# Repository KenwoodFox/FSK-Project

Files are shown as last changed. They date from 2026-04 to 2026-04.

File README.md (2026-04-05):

# FSK Analog Project

Done for EG330L at SNHU

# To Quickly Look At the design

Schematic [HERE](https://kicanvas.org/?repo=https://github.com/KenwoodFox/FSK-Project/blob/main/FSK%20Project.kicad_sch)  
PCB [HERE](https://kicanvas.org/?repo=https://github.com/KenwoodFox/FSK-Project/blob/main/FSK%20Project.kicad_pcb)

# To xmit the entire bee movie script
(the only valid benchmark ofc)

```shell
curl -s https://gist.githubusercontent.com/MattIPv4/045239bc27b16b2bcf7a3a9a4648c08a/raw/2411e31293a35f3e565f61e7490a806d4720ea7e/bee%2520movie%2520script | tee /dev/ttyUSB5
```

# Sending Serial/Testing

Configure Serial first

```shell
❯ minicom --device /dev/ttyUSB0 --baudrate 1200
```

Then you can cat+tee into the sender

```shell
❯ cat monk_syllabus.txt | tee /dev/ttyUSB0
```

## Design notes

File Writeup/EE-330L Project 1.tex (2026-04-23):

\documentclass[aspectratio=169]{beamer}
\usetheme{Berlin}

\usepackage{graphicx}
\usepackage{siunitx}
\usepackage{tikz}
\usepackage{qrcode}
% Do not store QR bitstrings in the .aux file (they are huge). A truncated .aux
% from an interrupted build causes ``File ended while scanning \qr@savematrix''.
% Tradeoff: each run recomputes QR codes (slightly slower, much more robust).
\makeatletter
\long\def\qr@writebinarymatrixtoauxfile#1{}%
\makeatother
\usepackage{acronym}

% Define acronyms without printing a list (immediate; \ac{...} works on first compile).
\newacro{FSK}{frequency-shift keying}
\newacro{PLL}{phase-locked loop}
\newacro{VCO}{voltage-controlled oscillator}

\title{Analog Project}
\subtitle{FSK Modulator and Demodulator}
\author{Joe Sedutto}
\institute{Southern New Hampshire University \and EE-330L --- Timothy Monk, Ph.D.}
\date{\today}

\begin{document}

\begin{frame}
  \titlepage
\end{frame}

\begin{frame}{Outline}
  \begin{columns}[T,onlytextwidth]
    \begin{column}{0.44\textwidth}
      \tableofcontents
    \end{column}
    \begin{column}{0.54\textwidth}
      \centering
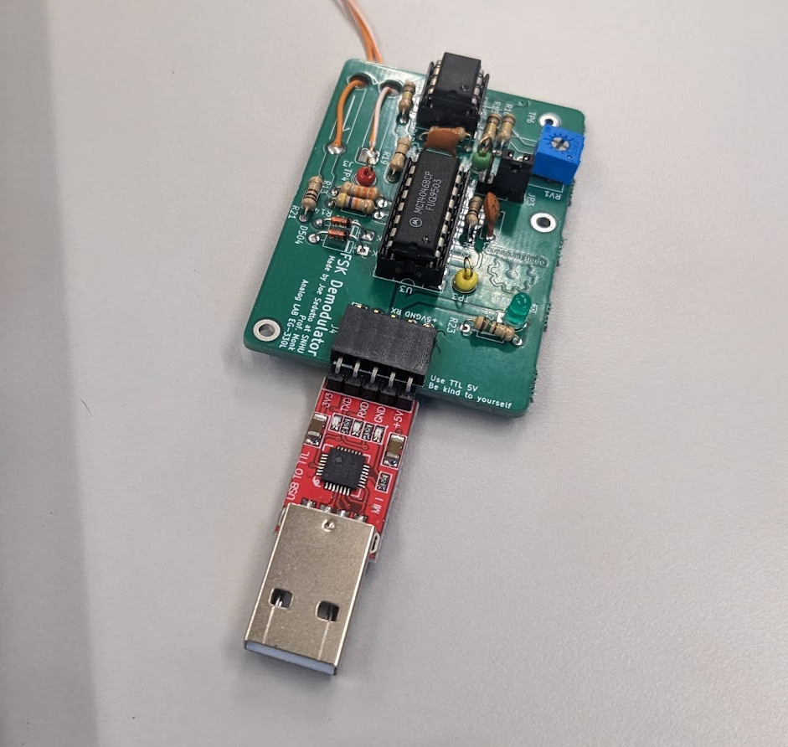
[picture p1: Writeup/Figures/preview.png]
      
    \end{column}
  \end{columns}
\end{frame}

%----------------------------------------------------------------------
\section{Introduction}

\begin{frame}{Introduction}
  The goal of the project was to design
  both an \ac{FSK} modulator and demodulator using a pair of \ac{PLL}s.

  \medskip
  A \ac{PLL} is a type of circuit that,  measures and reduces the phase offset between two
  incoming signals.
\end{frame}

\begin{frame}[fragile]{Basic PLL block diagram}
  \begin{figure}
    \centering
    \resizebox{\linewidth}{!}{%
    \begin{tikzpicture}[transform shape]
        \node[shape=rectangle, draw, line width=1pt, minimum width=2.965cm, minimum height=1.465cm] at (4.5, 10.25){};
        \node[shape=rectangle, draw, line width=1pt, minimum width=2.965cm, minimum height=1.465cm] at (8.5, 10.25){};
        \node[shape=rectangle, draw, line width=1pt, minimum width=2.965cm, minimum height=1.465cm] at (12.5, 10.25){};
        \node[shape=rectangle, draw, line width=1pt, minimum width=2.965cm, minimum height=1.465cm] at (8.5, 7.25){};
        \draw[-latex] (6, 10.25) -- (7, 10.25);
        \draw[-latex] (10, 10.25) -- (11, 10.25);
        \draw[-latex] (14, 10.25) -- (16, 10.25);
        \draw[-latex] (15, 10.25) |- (10, 7.25);
        \draw[-latex] (1.5, 10.5) -- (3, 10.5);
        \draw[-latex] (7, 7.25) -| (1.5, 10) -- (3, 10);
        \node[shape=rectangle, minimum width=2.965cm, minimum height=1.465cm] at (4.5, 10.25){} node[anchor=center, align=center, text width=2.577cm, inner sep=6pt] at (4.5, 10.25){Phase Detector};
        \node[shape=rectangle, minimum width=2.965cm, minimum height=1.465cm] at (8.5, 10.25){} node[anchor=center, align=center, text width=2.577cm, inner sep=6pt] at (8.5, 10.25){Filter};
        \node[shape=rectangle, minimum width=2.965cm, minimum height=1.465cm] at (12.5, 10.25){} node[anchor=center, align=center, text width=2.577cm, inner sep=6pt] at (12.5, 10.25){Voltage Controlled Oscillator};
        \node[shape=rectangle, minimum width=2.965cm, minimum height=1.465cm] at (8.5, 7.25){} node[anchor=center, align=center, text width=2.577cm, inner sep=6pt] at (8.5, 7.25){Feedback Divider};
        \node[shape=rectangle, minimum width=0.965cm, minimum height=0.465cm] at (1.5, 11){} node[anchor=north west, align=left, text width=0.577cm, inner sep=6pt] at (1, 11.25){$F_\text{ref}$};
        \node[shape=rectangle, minimum width=0.965cm, minimum height=0.465cm] at (16, 10.75){} node[anchor=north west, align=left, text width=0.577cm, inner sep=6pt] at (15.5, 11){$F_\text{ref}$};
    \end{tikzpicture}%
    }
    \label{fig:pll-block}
  \end{figure}
\end{frame}

%----------------------------------------------------------------------
\section{Input}

\begin{frame}{Input signal and level shifting}
  I wanted to design the FSK pair around transmitting something simple.
  TTL-logic via USB seemed like a good choice.

  \medskip
  There are many common baud rates for serial communication; I initially designed around 9600baud.
\end{frame}

\begin{frame}{Symbol Rate and Bandwidth}
  \begin{equation}
    f_\text{symbol} \leq \frac{1}{10} \cdot \text{Loop Bandwidth}
  \end{equation}

  at 100\,kHz\footnote{couple other factors like maximum catchup/slew rate and also the \ac{PLL} seek time},

  \begin{equation}
    f_\text{symbol} \leq \frac{1}{10} \cdot 100\text{k} = 10\text{kHz} \approx 9600\,\text{baud}
  \end{equation}
\end{frame}

\section{Level Shifter}
\begin{frame}{level shifter}
  \begin{figure}
    \centering
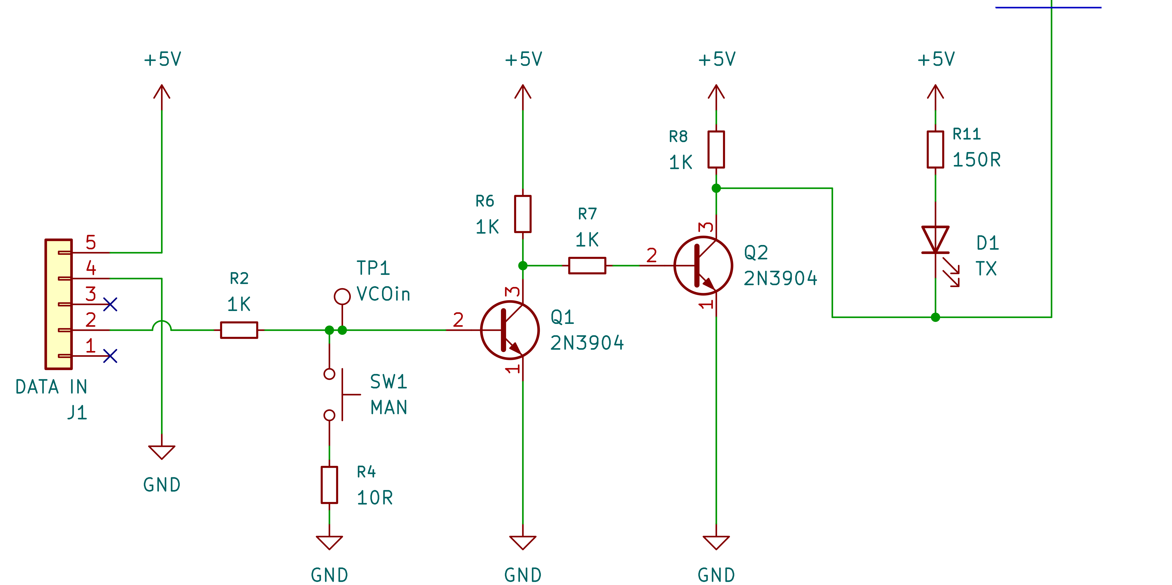
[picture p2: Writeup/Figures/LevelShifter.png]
    
    \label{fig:level-shifter}
  \end{figure}
\end{frame}

\begin{frame}[fragile]{Choosing Symbol Frequencies}
  \begin{figure}
    \centering
    \resizebox{0.7\linewidth}{!}{%
    \begin{tikzpicture}
        \draw[->] (0,0) -- (8,0) node[right] {Frequency (Hz)};
        \draw[->] (0,0) -- (0,5.5) node[above] {Voltage (V)};
        \draw (0,0) -- (0,-0.15) node[below] {88k};
        \draw (2,0) -- (2,-0.15) node[below] {92k};
        \draw (4,0) -- (4,-0.15) node[below] {104k};
        \draw (6,0) -- (6,-0.15) node[below] {112k};
        \draw (8,0) -- (8,-0.15) node[below] {120k};
        \draw (0,1) -- (-0.15,1) node[left] {1};
        \draw (0,2.5) -- (-0.15,2.5) node[left] {2.5};
        \draw (0,4.5) -- (-0.15,4.5) node[left] {4.5};
        \draw (0,5) -- (-0.15,5) node[left] {5};
        \draw[red, dashed, thick] (0,1) -- (8,1);
        \draw[red, dashed, thick] (0,4.5) -- (8,4.5);
        \draw[black, dashed, thick] (0,0) -- (8,5) node[above right] {PLL Freq.};
    \end{tikzpicture}%
    }
  \end{figure}
\end{frame}

\section{PLL modulator}

\begin{frame}{PLL modulator}
  \begin{figure}
    \centering
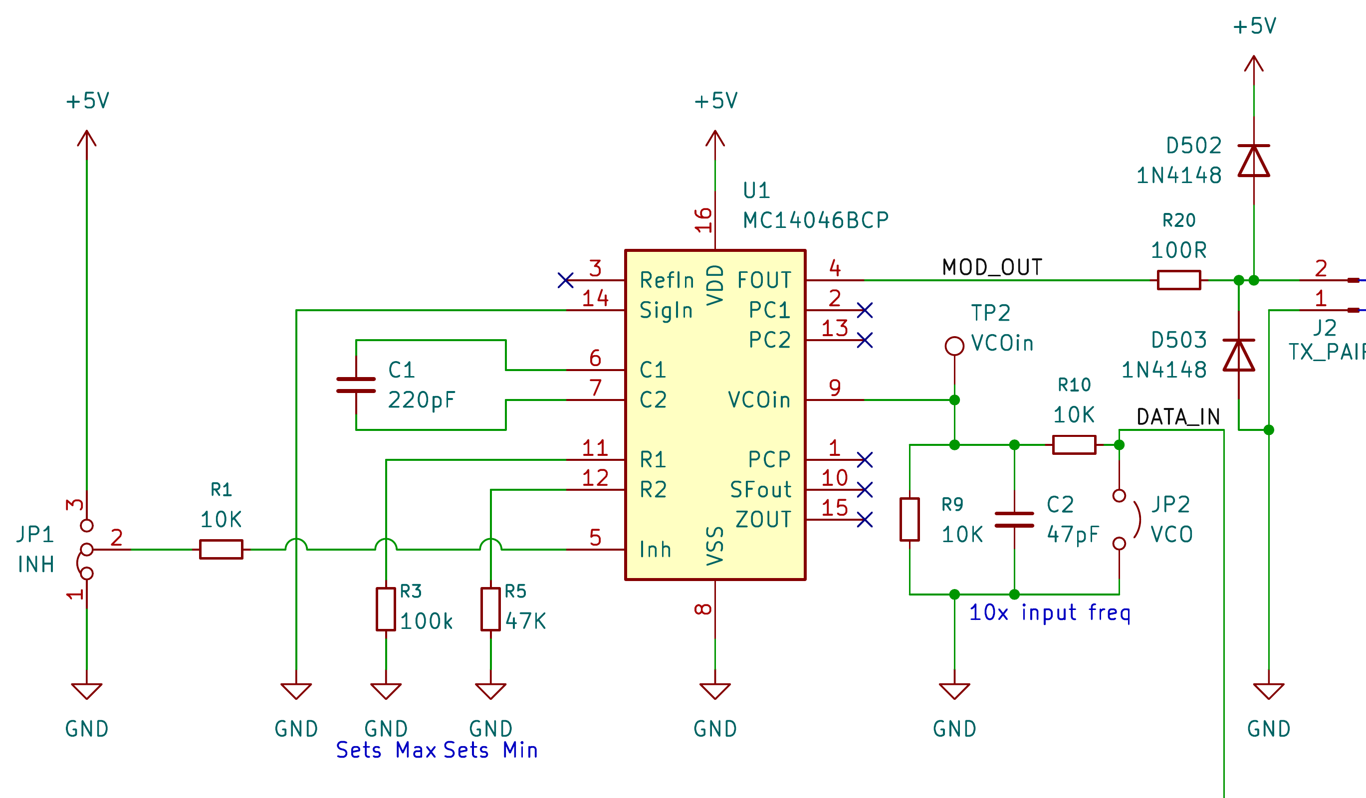
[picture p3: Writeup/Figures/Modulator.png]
    
  \end{figure}
\end{frame}

\begin{frame}{PLL modulator}
  \begin{figure}
    \centering
    \def\ModHlCx{0.32}% center x
    \def\ModHlCy{0.25}% center y
    \def\ModHlW{0.08}% half-width
    \def\ModHlH{0.08}% half-height
    \begin{tikzpicture}
      \node[anchor=south west, inner sep=0] (modimg) at (0,0)
        {};
      \begin{scope}[x={(modimg.south east)}, y={(modimg.north west)}]
        \draw[draw=orange!90!black, line width=1.6pt, fill=yellow!70, fill opacity=0.35, rounded corners=2pt]
          ({\ModHlCx-\ModHlW},{\ModHlCy-\ModHlH}) rectangle ({\ModHlCx+\ModHlW},{\ModHlCy+\ModHlH});
      \end{scope}
    \end{tikzpicture}
  \end{figure}
\end{frame}

\begin{frame}{PLL modulator}
  $R3$ and $R5$ Set the \textbf{limits} for the pll loop speeds on the (same on demodulator too)

  Reducing the headroom/bandwidth for the PLL max speed helped overall

  Original resistor sizes were specified for the target symbol diversity I wanted.

  \begin{align}
    R_3 &= \qty{47}{\kilo\ohm}  \qquad f_{\mathrm{min}} = \qty{84.4}{\kilo\hertz} \\
    R_5 &= \qty{100}{\kilo\ohm} \qquad f_{\mathrm{min}} = \qty{100.0}{\kilo\hertz}
  \end{align}
\end{frame}

\section{PLL demodulator}

\begin{frame}{PLL demodulator}
  \begin{itemize}
    \item Demodulator was harder than the modulator
    \item Two problems dominated, it was hard to differentiate between symbols
    \item Getting a PLL lock was trickier especially without limiters
  \end{itemize}
\end{frame}

\begin{frame}{PLL demodulator}
  \begin{figure}
    \centering
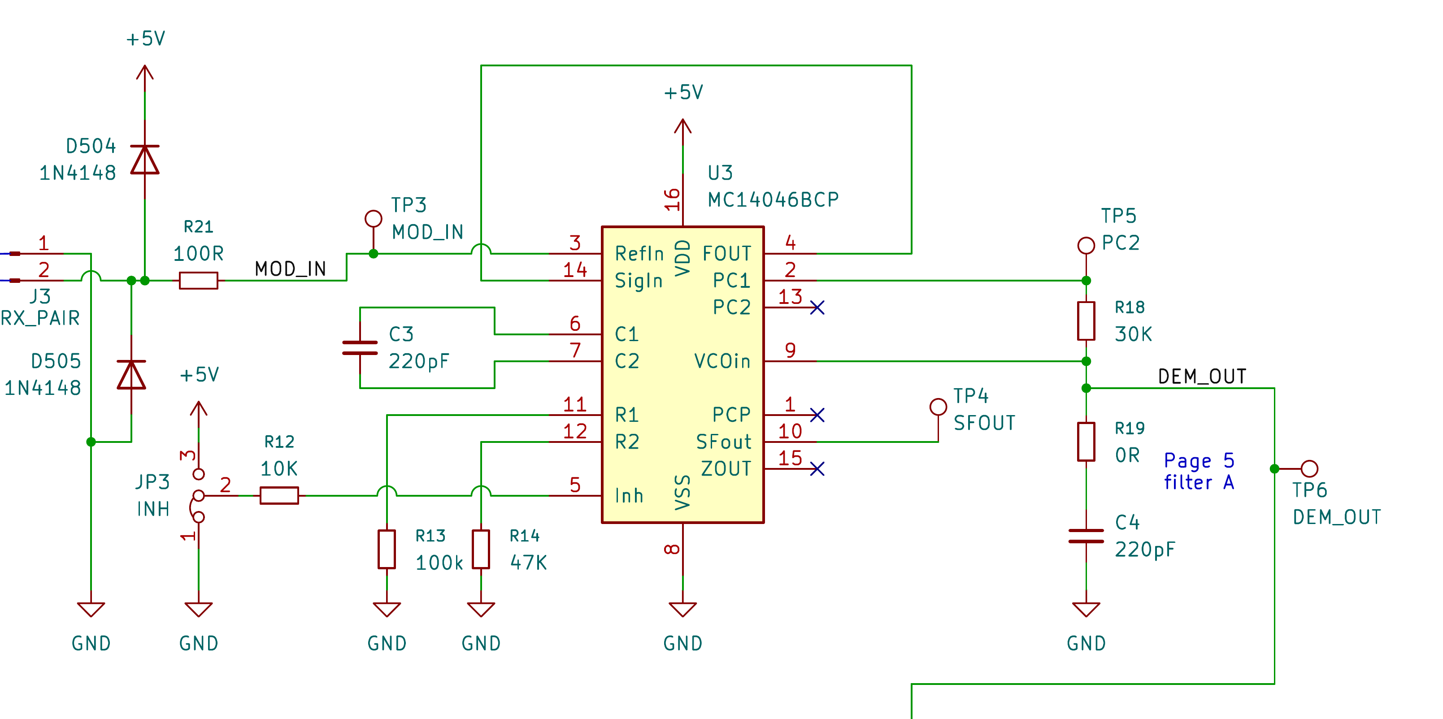
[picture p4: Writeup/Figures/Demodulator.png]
    
  \end{figure}
\end{frame}

\begin{frame}{PLL synchronization}
  \begin{figure}
    \centering
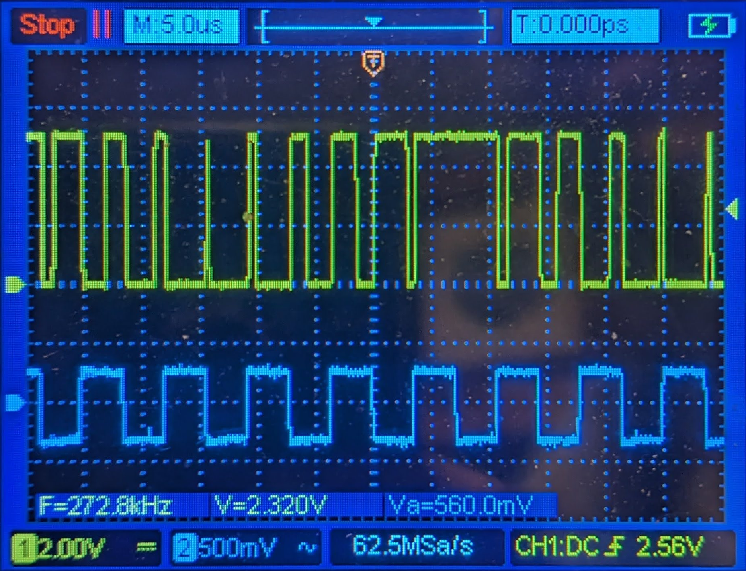
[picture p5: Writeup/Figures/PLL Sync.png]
    
  \end{figure}
\end{frame}

\section{Output filtering and Schmitt trigger}

\begin{frame}{Schmitt trigger}
  \begin{figure}
    \centering
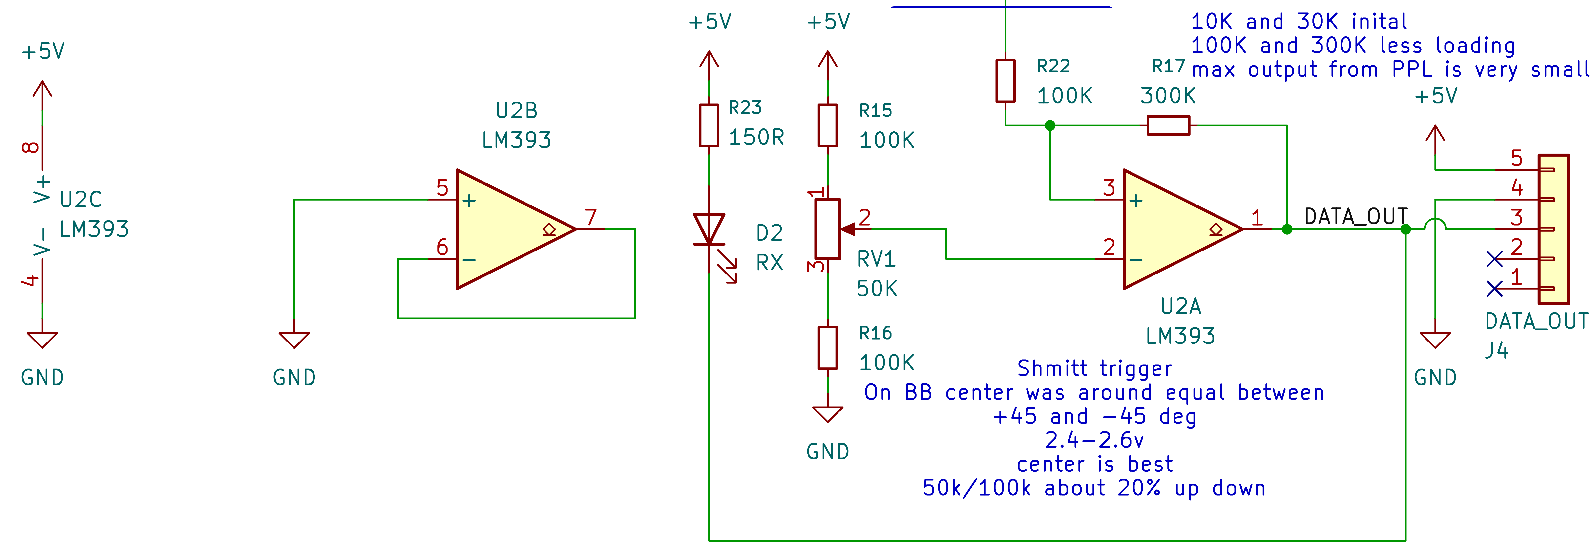
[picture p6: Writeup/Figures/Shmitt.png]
    
  \end{figure}
\end{frame}

\begin{frame}{Schmitt trigger}
  \begin{figure}
    \centering
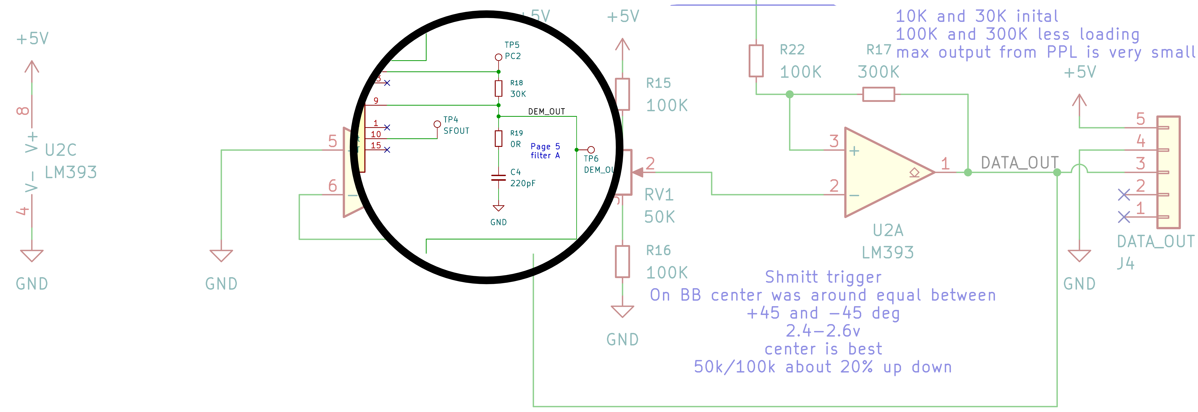
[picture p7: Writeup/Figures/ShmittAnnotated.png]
    
  \end{figure}
\end{frame}

\begin{frame}{Schmitt trigger}
  \begin{figure}
    \centering
    
  \end{figure}
\end{frame}

\begin{frame}{Damping factor}
  \begin{columns}[T,onlytextwidth]
    \begin{column}{0.44\textwidth}
      $N = 1$; \quad
      $k_\phi$\footnote{Datasheet; different passive loop filter in hardware.},
      $k_\text{VCO}$\footnote{Datasheet; varies with frequency offset and $V_\mathrm{CC}$.}

      \medskip
      $\zeta = \num{0.707}$ target \quad $\Rightarrow$ \quad $\zeta \approx \num{0.621}$ as built

      \medskip
      {\footnotesize\textit{Note:} PC1 has better noise immunity, which influenced the loop-filter choice.}
    \end{column}
    \begin{column}{0.54\textwidth}
      \centering
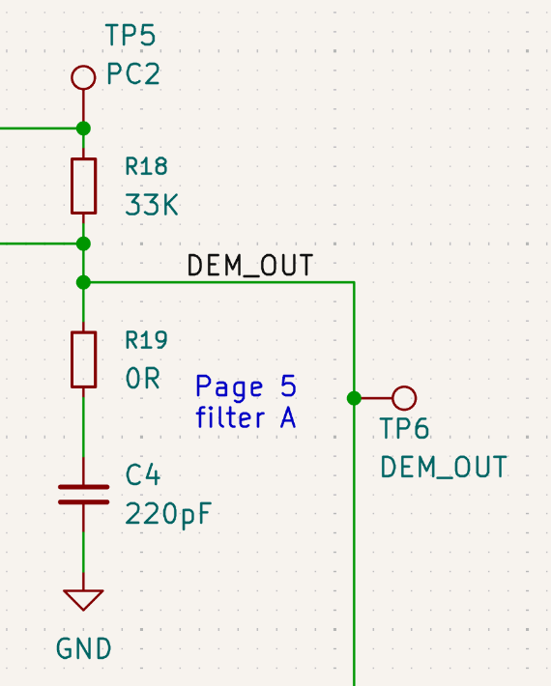
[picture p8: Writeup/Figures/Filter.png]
      
    \end{column}
  \end{columns}
\end{frame}

\section{Other}

\begin{frame}{Other Thoughts on the class overall}
 \begin{itemize}
  \item Labs were interesting and challenging
  \item A little odd that the project counted for so much of the grade
  \item Open ended projects was nice
 \end{itemize}
\end{frame}

%----------------------------------------------------------------------
\section{Resources}

\begin{frame}[fragile]{Links}
  \scriptsize
  \begin{columns}[T]
    \begin{column}{0.48\linewidth}
      \begin{itemize}
        \item \qrcode[height=0.5in]{https://github.com/KenwoodFox/FSK-Project/}\\FSK Project (GitHub)
        \item \qrcode[height=0.5in]{https://kicanvas.org/?repo=https://github.com/KenwoodFox/FSK-Project/blob/main/FSK%20Project.kicad_sch}\\Schematic (KiCanvas)
      \end{itemize}
    \end{column}
    \begin{column}{0.48\linewidth}
      \begin{itemize}
        \item \qrcode[height=0.5in]{https://kicanvas.org/?repo=https://github.com/KenwoodFox/FSK-Project/blob/main/FSK%20Project.kicad_pcb}\\PCB (KiCanvas)
        \item \qrcode[height=0.5in]{https://www.ti.com/lit/an/slaa618/slaa618.pdf}\\TI SLAA618
      \end{itemize}
    \end{column}
  \end{columns}
\end{frame}

\begin{frame}{Acronyms}
  \begin{description}
    \item[FSK] frequency-shift keying
    \item[PLL] phase-locked loop
    \item[VCO] voltage-controlled oscillator
  \end{description}
\end{frame}

\end{document}

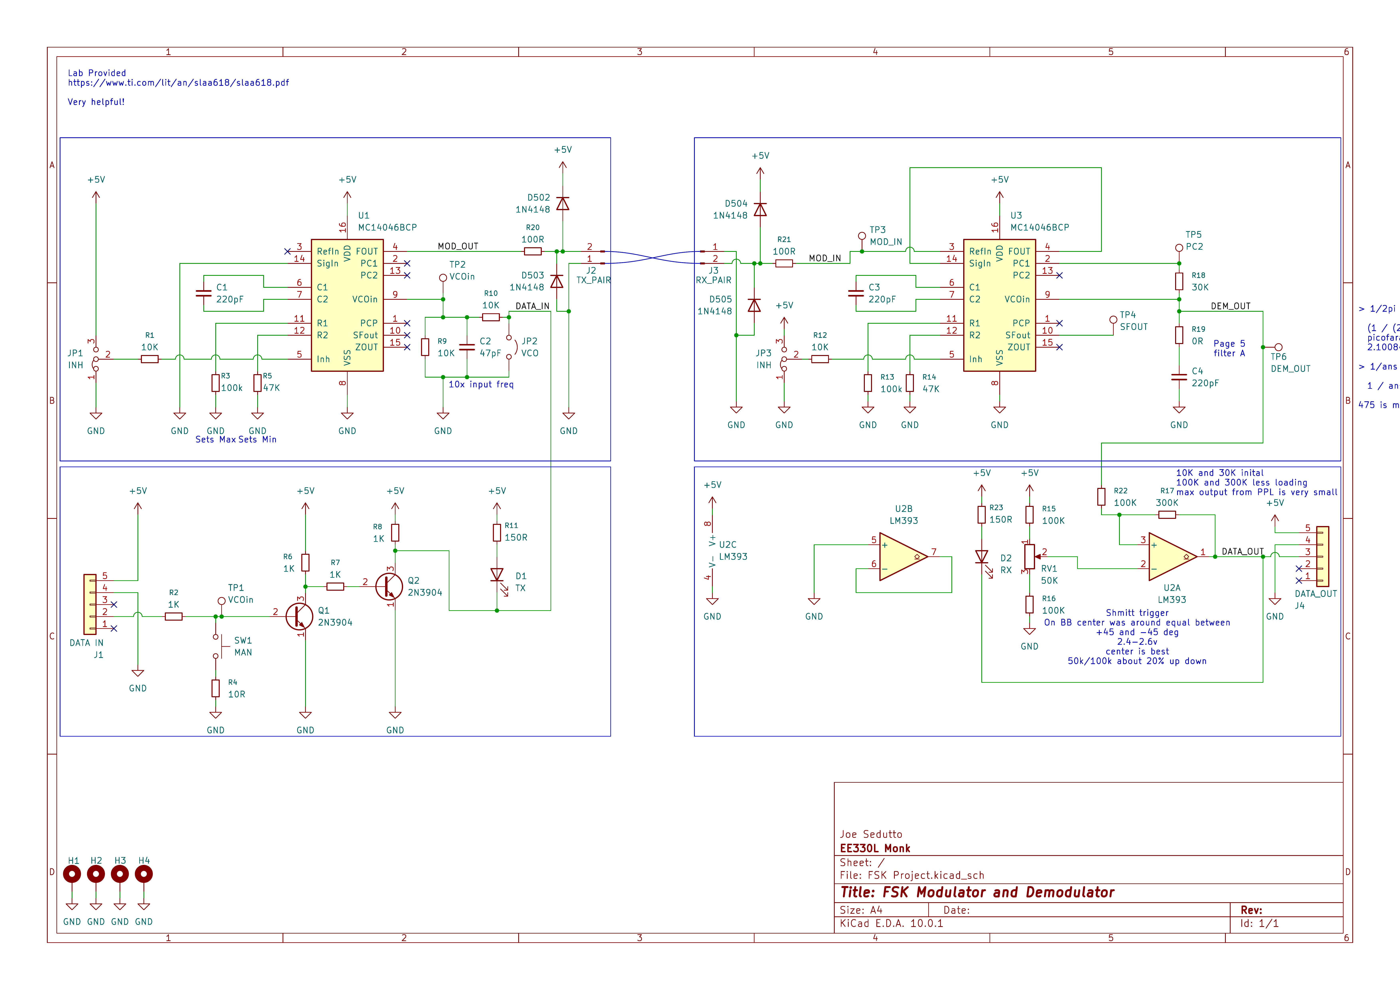
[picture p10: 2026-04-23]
Writeup/Figures/FSKProject.png

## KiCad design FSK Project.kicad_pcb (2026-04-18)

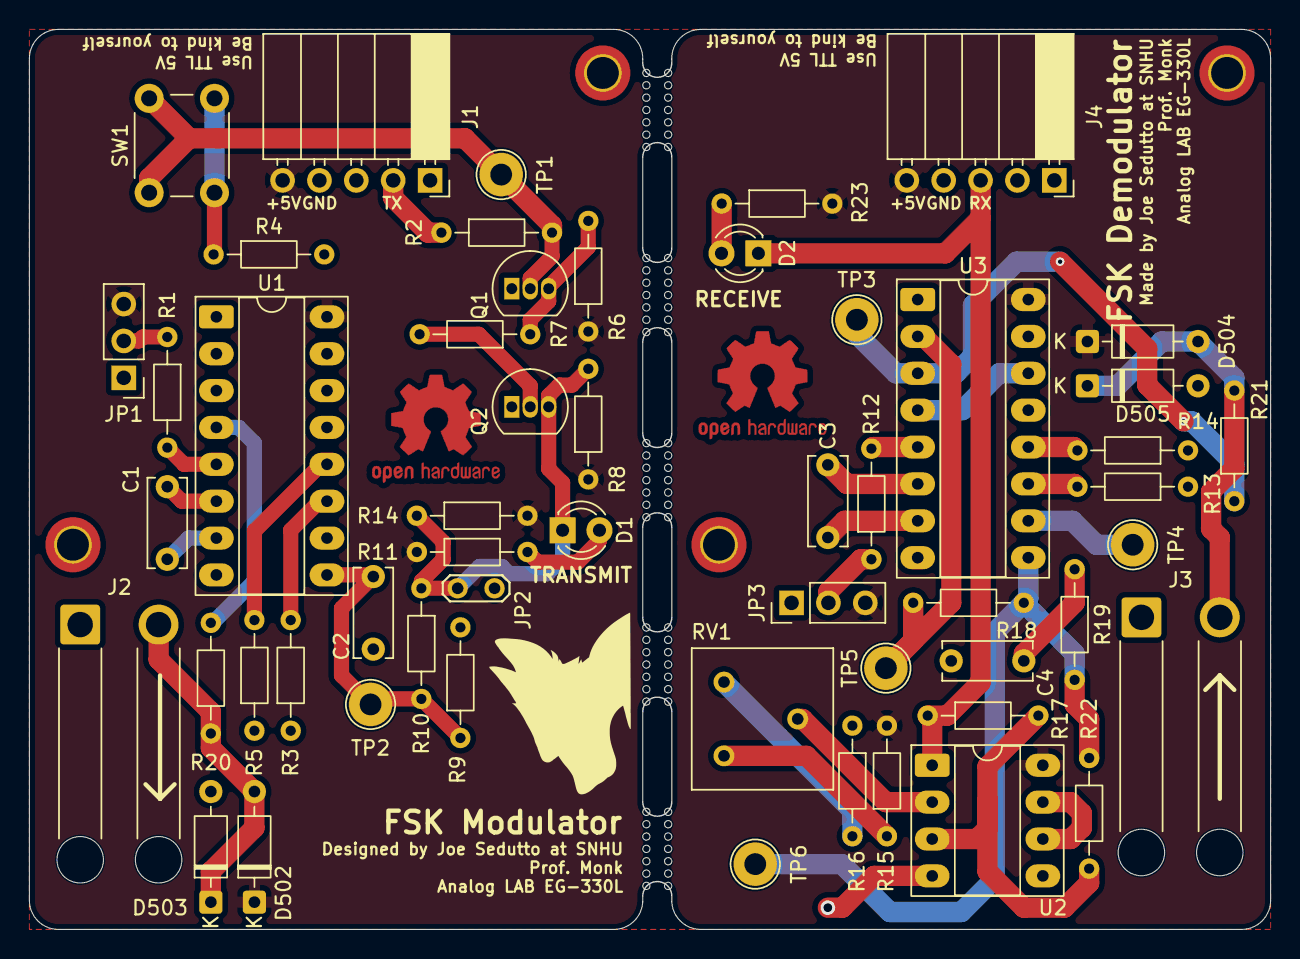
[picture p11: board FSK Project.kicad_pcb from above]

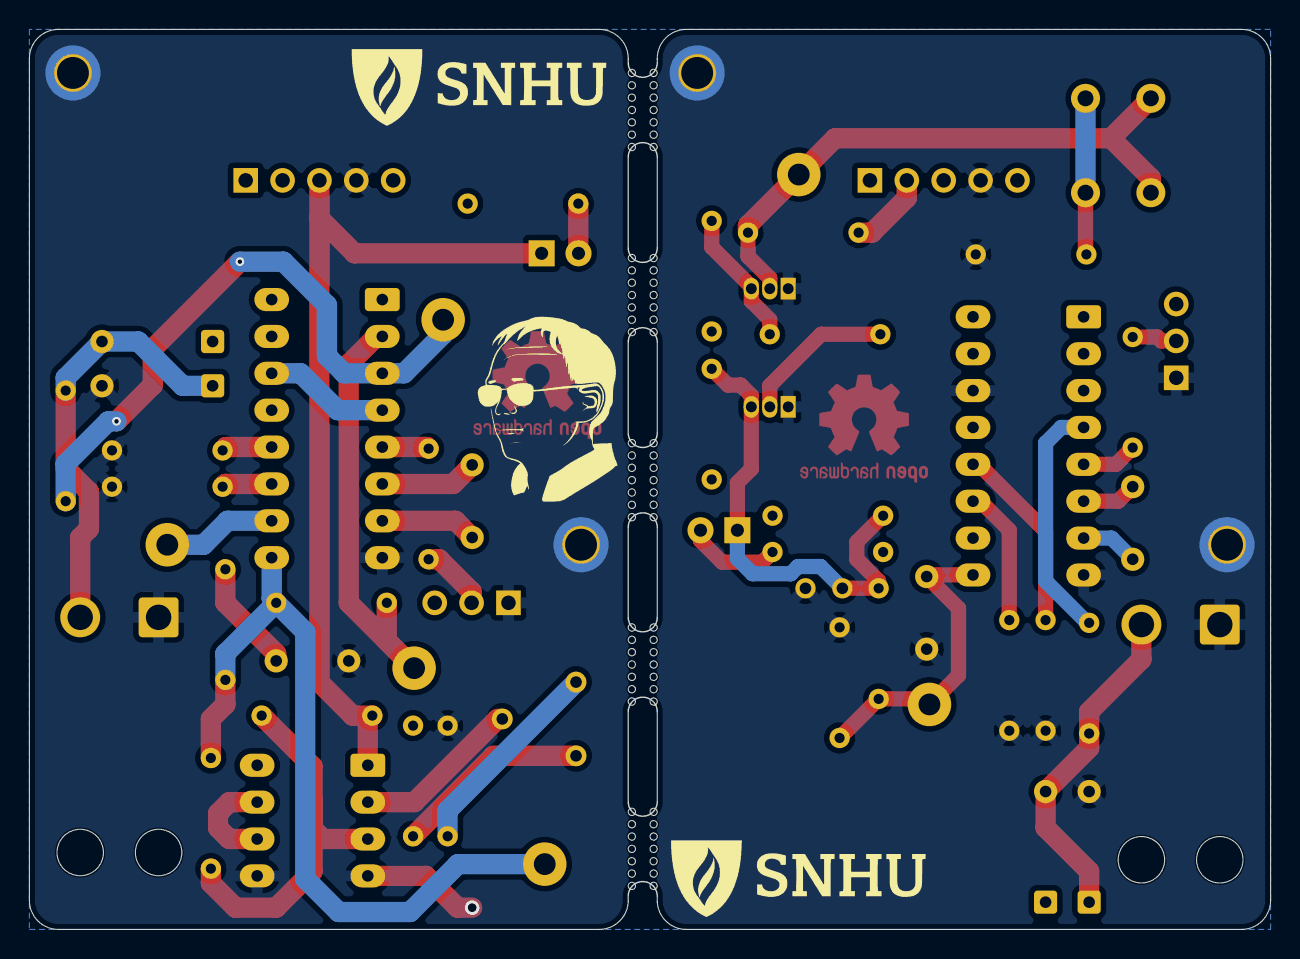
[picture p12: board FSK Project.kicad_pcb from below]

Board: 2 copper layers, 85.5 x 62.0 mm, 60 parts (2 on the bottom side), 38 nets.

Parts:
C1, C3, C4: 220pF; C_Disc_D6.0mm_W2.5mm_P5.00mm
C2: 47pF; C_Disc_D6.0mm_W2.5mm_P5.00mm
D1: TX; LED_D3.0mm
D2: RX; LED_D3.0mm
D502, D503, D504, D505: 1N4148; D_DO-35_SOD27_P7.62mm_Horizontal
H1, H2, H3, H4: MountingHole_Pad; MountingHole_2.2mm_M2_DIN965_Pad_TopBottom
J1: DATA IN; PinSocket_1x05_P2.54mm_Horizontal
J2: TX_PAIR; SolderWire-1sqmm_1x02_P5.4mm_D1.4mm_OD2.7mm_Relief
J3: RX_PAIR; SolderWire-1sqmm_1x02_P5.4mm_D1.4mm_OD2.7mm_Relief
J4: DATA_OUT; PinSocket_1x05_P2.54mm_Horizontal
JP1, JP3: INH; PinHeader_1x03_P2.54mm_Vertical
JP2: VCO; TestPoint_2Pads_Pitch2.54mm_Drill0.8mm
Q1, Q2: 2N3904; TO-92_Inline
R1, R9, R10, R12: 10K; R_Axial_DIN0204_L3.6mm_D1.6mm_P7.62mm_Horizontal
R2, R6, R7, R8: 1K; R_Axial_DIN0204_L3.6mm_D1.6mm_P7.62mm_Horizontal
R3, R13: 100k; R_Axial_DIN0204_L3.6mm_D1.6mm_P7.62mm_Horizontal
R4: 10R; R_Axial_DIN0204_L3.6mm_D1.6mm_P7.62mm_Horizontal
R5, R14#2: 47K; R_Axial_DIN0204_L3.6mm_D1.6mm_P7.62mm_Horizontal
R11, R23: 150R; R_Axial_DIN0204_L3.6mm_D1.6mm_P7.62mm_Horizontal
R14: 510K; R_Axial_DIN0204_L3.6mm_D1.6mm_P7.62mm_Horizontal
R15, R16, R22: 100K; R_Axial_DIN0204_L3.6mm_D1.6mm_P7.62mm_Horizontal
R17: 300K; R_Axial_DIN0204_L3.6mm_D1.6mm_P7.62mm_Horizontal
R18: 30K; R_Axial_DIN0204_L3.6mm_D1.6mm_P7.62mm_Horizontal
R19: 0R; R_Axial_DIN0204_L3.6mm_D1.6mm_P7.62mm_Horizontal
R20, R21: 100R; R_Axial_DIN0204_L3.6mm_D1.6mm_P7.62mm_Horizontal
RV1: 50K; Potentiometer_Bourns_3386F_Vertical
SNHU_NEW***: LOGO; SNHU_NEW
SNHU_NEW***#2: LOGO; SNHU_NEW
SW1: MAN; SW_PUSH_6mm
TP1, TP2: VCOin; TestPoint_Loop_D2.54mm_Drill1.5mm_Beaded
TP3: MOD_IN; TestPoint_Loop_D2.54mm_Drill1.5mm_Beaded
TP4: SFOUT; TestPoint_Loop_D2.54mm_Drill1.5mm_Beaded
TP5: PC2; TestPoint_Loop_D2.54mm_Drill1.5mm_Beaded
TP6: DEM_OUT; TestPoint_Loop_D2.54mm_Drill1.5mm_Beaded
U1, U3: MC14046BCP; DIP-16_W7.62mm_Socket_LongPads
U2: LM393; DIP-8_W7.62mm_Socket_LongPads

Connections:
+5V: D502.1 (K), D504.1 (K), J1.5, J4.5, JP1.3 (B), JP3.3 (B), R6.1, R8.1, R11.2, R14.2, R15.2, R23.2, U1.16 (VDD), U2.8 (V+), U3.16 (VDD)
/DATA_IN: D1.1 (K), JP2.1 (A), Q2.3 (C), R8.2, R10.1, R14.1
/DATA_OUT: D2.1 (K), J4.3, R17.1, U2.1
/DEM_OUT: R18.1, R19.2, R22.2, TP6.1 (1_1), U3.9 (VCOin)
/MOD_IN: R21.1, TP3.1 (1_1), U3.3 (RefIn)
/MOD_OUT: R20.2, U1.4 (FOUT)
GND: C2.2, C4.2, D503.2 (A), D505.2 (A), H1.1 (1_1), H2.1 (1_1), H3.1 (1_1), H4.1 (1_1), J1.4, J2.1, J3.1, J4.4, JP1.1 (A), JP2.2 (B), JP3.1 (A), Q1.1 (E), Q2.1 (E), R3.1, R4.2, R5.1, R9.2, R13.1, R14#2.1, R16.1, U1.8 (VSS), U1.14 (SigIn), U2.4 (V-), U2.5 (+), U3.8 (VSS)
unnamed: C4.1, R19.1
unnamed: D1.2 (A), R11.1
unnamed: D2.2 (A), R23.1
unnamed: D502.2 (A), D503.1 (K), J2.2, R20.1
unnamed: D504.2 (A), D505.1 (K), J3.2, R21.2
unnamed: J1.2, R2.1
unnamed: JP1.2 (C), R1.1
unnamed: JP3.2 (C), R12.1
unnamed: Q1.2 (B), R2.2, SW1.1, TP1.1 (1_1)
unnamed: Q1.3 (C), R6.2, R7.1
unnamed: Q2.2 (B), R7.2
unnamed: R4.1, SW1.2
unnamed: R15.1, RV1.1
unnamed: R16.2, RV1.3
unnamed: C1.1, U1.6 (C1)
unnamed: C1.2, U1.7 (C2)
unnamed: R1.2, U1.5 (Inh)
unnamed: R3.2, U1.11 (R1)
unnamed: R5.2, U1.12 (R2)
unnamed: C2.1, R9.1, R10.2, TP2.1 (1_1), U1.9 (VCOin)
unnamed: R17.2, R22.1, U2.3 (+)
unnamed: RV1.2, U2.2 (-)
unnamed: U2.6 (-), U2.7
unnamed: C3.1, U3.6 (C1)
unnamed: C3.2, U3.7 (C2)
unnamed: U3.4 (FOUT), U3.14 (SigIn)
unnamed: R12.2, U3.5 (Inh)
unnamed: R18.2, TP5.1 (1_1), U3.2 (PC1)
unnamed: R13.2, U3.11 (R1)
unnamed: R14#2.2, U3.12 (R2)
unnamed: TP4.1 (1_1), U3.10 (SFout)

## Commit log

2026-04-02 Add page 5 filter information
    [FSK Project.kicad_pcb, FSK Project.kicad_sch]
2026-04-02 Add static protection
    [FSK Project.kicad_pcb, FSK Project.kicad_sch]
2026-04-02 Add outputs/gerbers for prod:
    [FSK Project.kicad_pcb]
2026-04-02 Add final libs, include last leftover bits, fix op-amp and verify on board
    [FSK Project.kicad_pcb, FSK Project.kicad_sch]
2026-04-02 Export gerbers
    [FSK Project.kicad_pcb, FSK Project.kicad_sch]
2026-04-03 Add cool cutouts for ground probe grabs on back copper, not needed here but its neat
    [FSK Project.kicad_pcb]
2026-04-07 Get the writeup started
    [FSK Project.kicad_pcb]
2026-04-18 fix some issues i made in the design oops
    [FSK Project.kicad_pcb, FSK Project.kicad_sch]
2026-04-23 Finish before class
    [FSK Project.kicad_sch]
